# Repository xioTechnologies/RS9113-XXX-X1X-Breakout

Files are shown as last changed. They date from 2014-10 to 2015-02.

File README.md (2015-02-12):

RS9113-XXX-X1X-Breakout
=======================

Breakboard for the Redpine Signals [RS9113-XXX-X1X](http://www.redpinesignals.com/Modules/Internet_of_Things/Connection_Family/RS9113.php) Wi-Fi module.  Includes pull-down resistors as per datasheet.

The silkscreen overlaps copper pads with the intention that this is corrected by the PCB fabrication supplier.

Photo (with connections for UART)
---------------------------------


PCB Preview from OSH Park
-------------------------
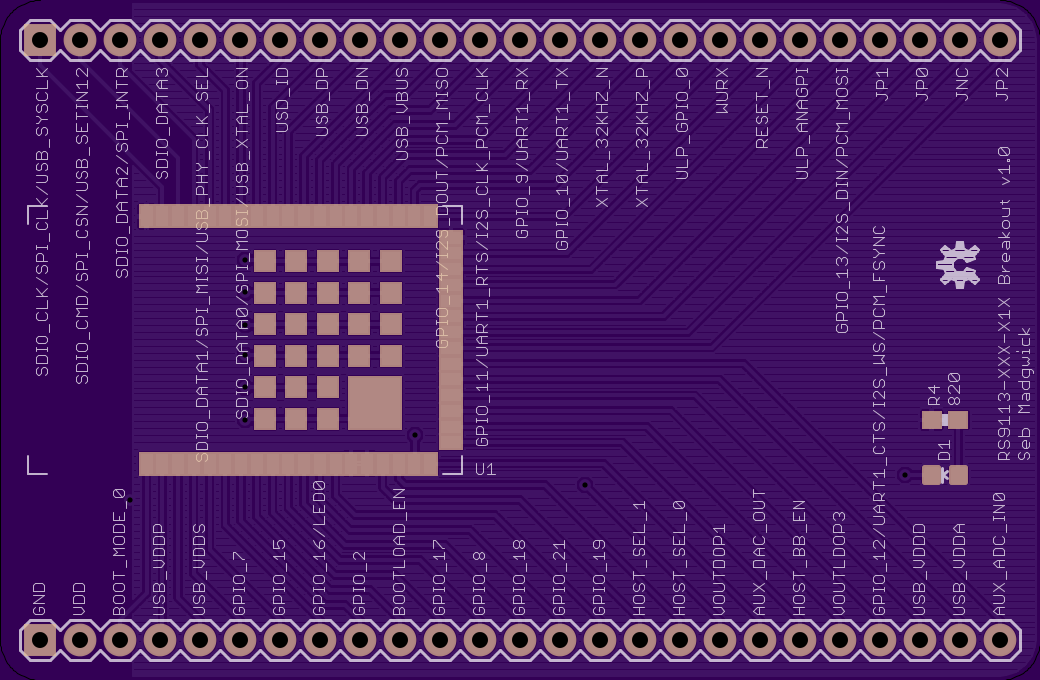
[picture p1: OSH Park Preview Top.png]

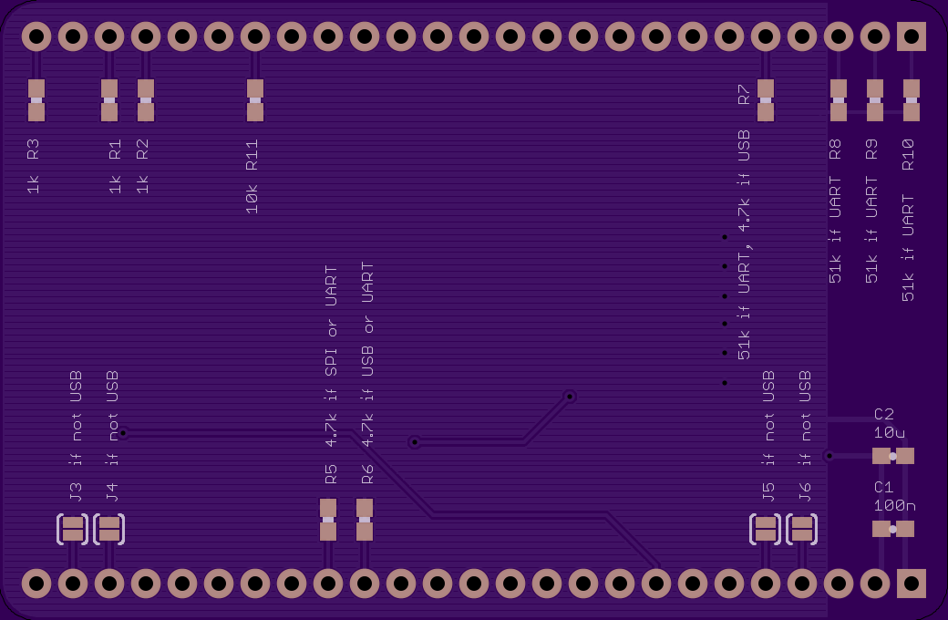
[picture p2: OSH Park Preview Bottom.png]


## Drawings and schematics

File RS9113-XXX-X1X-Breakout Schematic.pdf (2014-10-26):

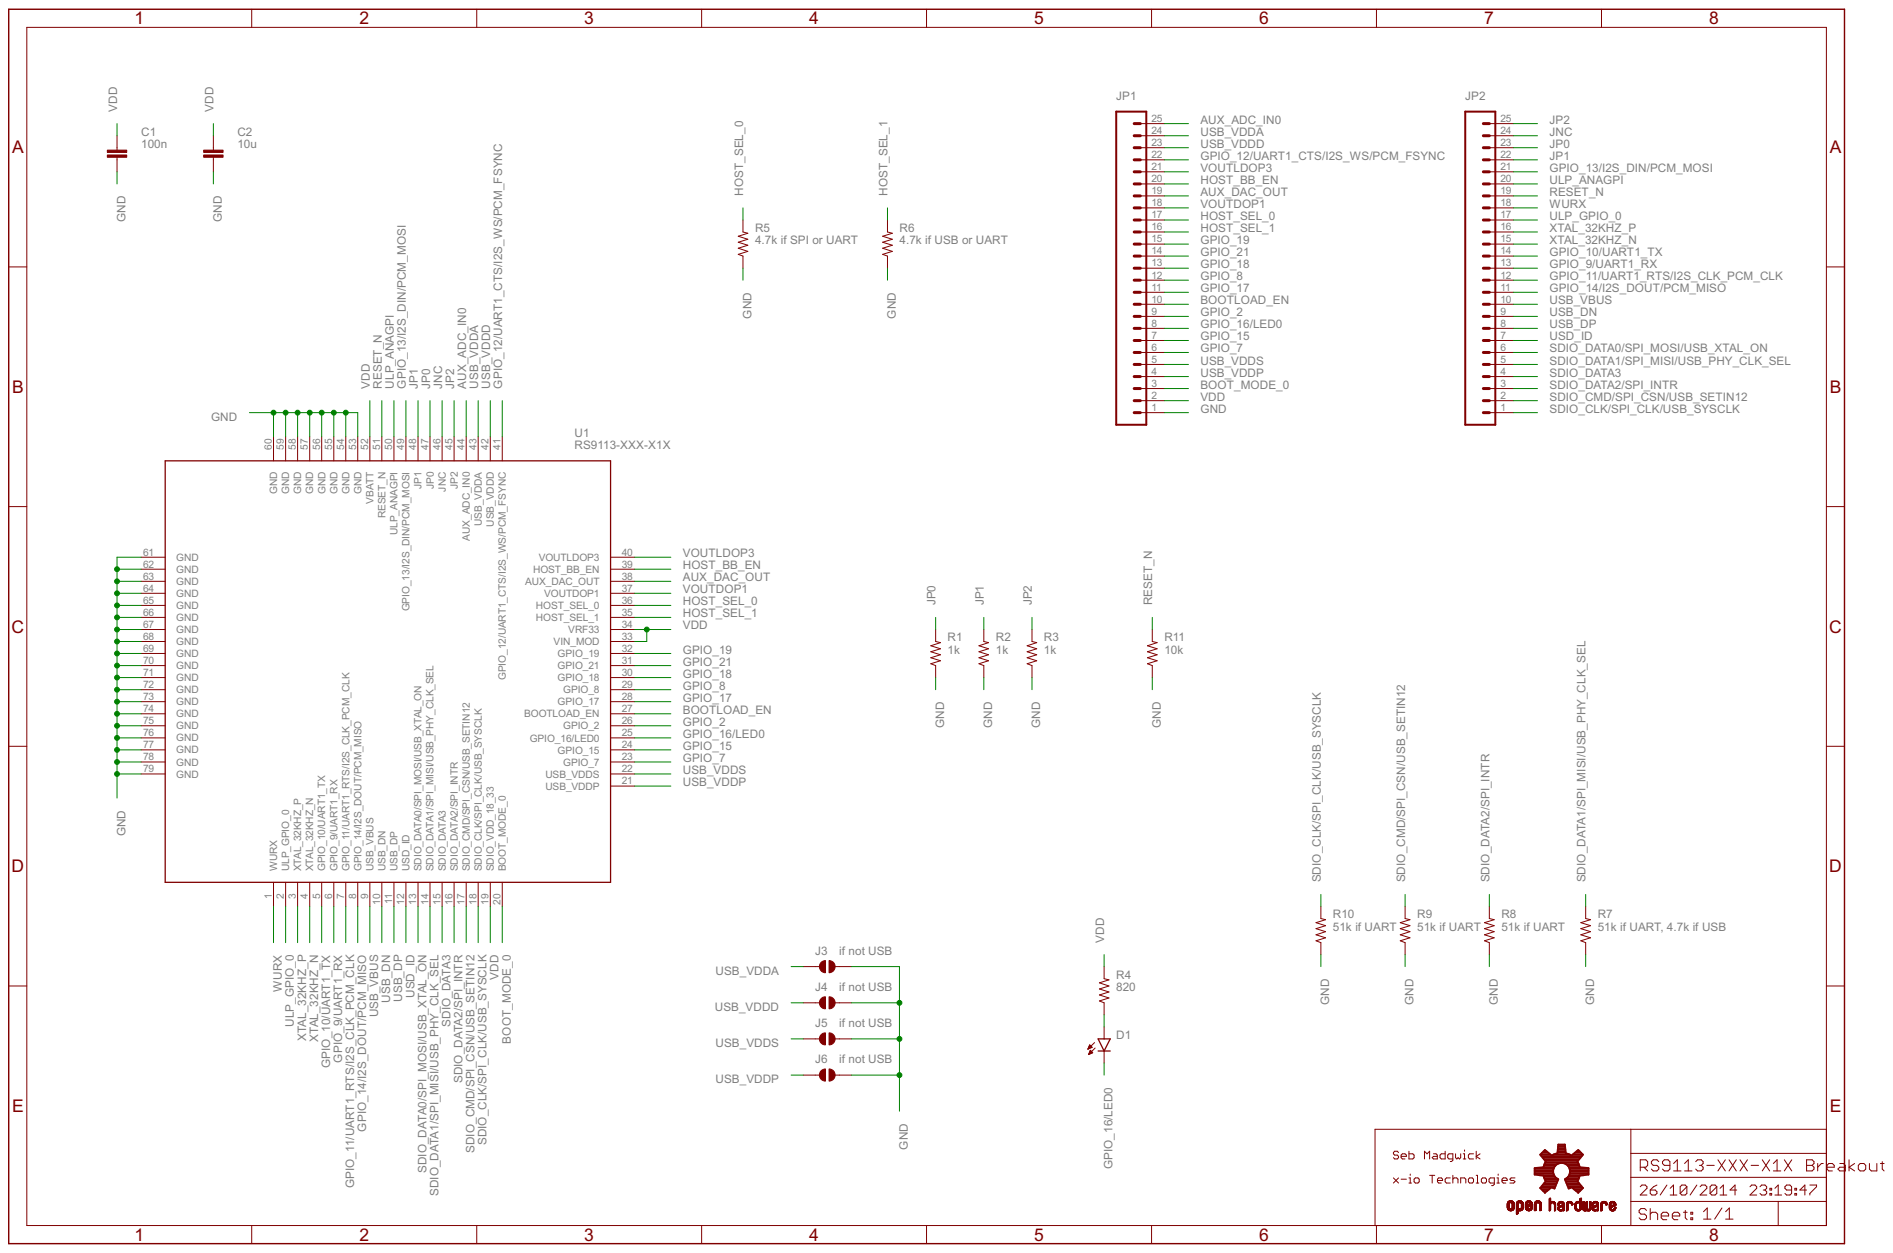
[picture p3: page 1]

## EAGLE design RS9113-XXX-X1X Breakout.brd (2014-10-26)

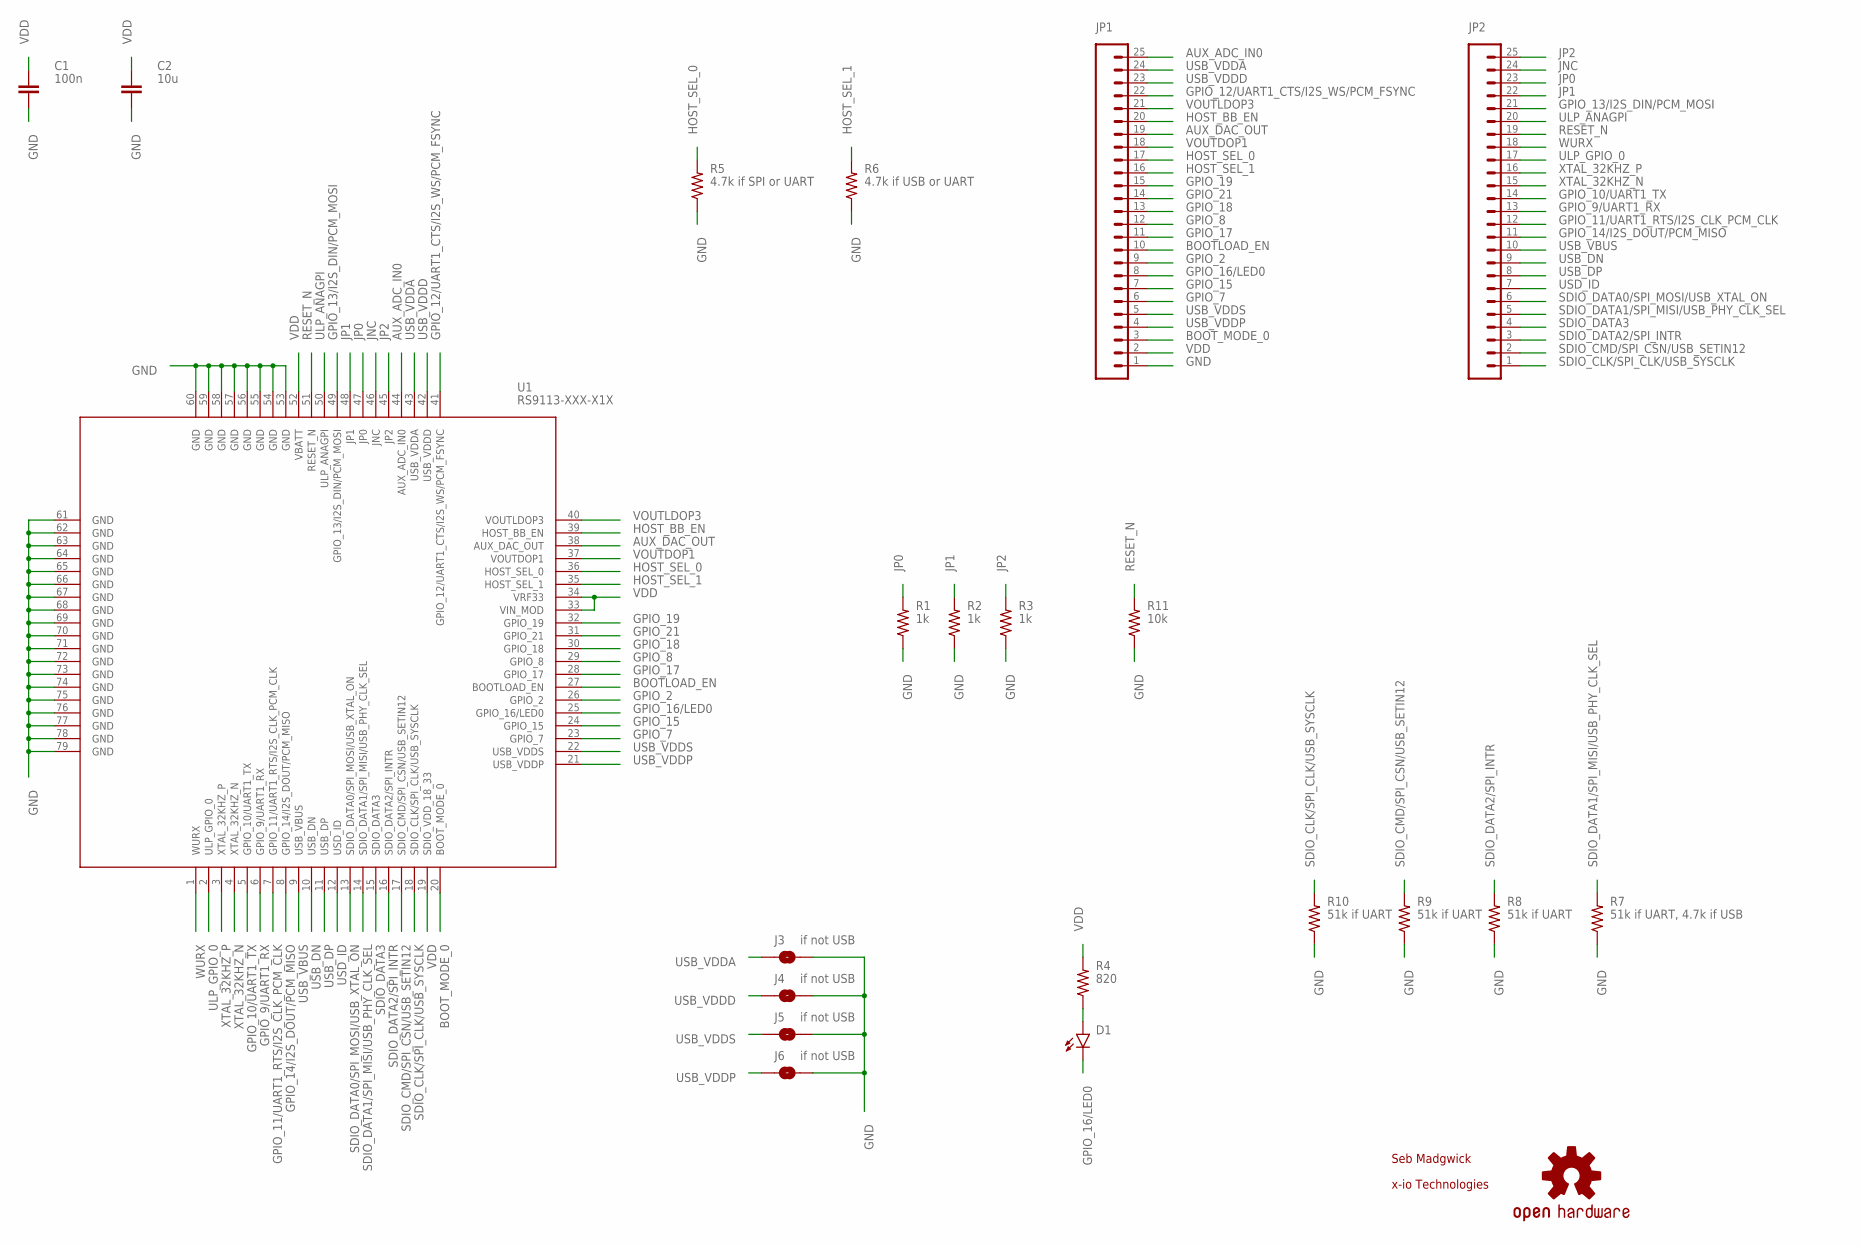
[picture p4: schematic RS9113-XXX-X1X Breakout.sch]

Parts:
C1: 100n; 0603-CAP
C2: 10u; 0603-CAP
D1: GREEN; LED-0603
J3, J4, J5, J6: if not USB; SJ_2S-NO
JP1, JP2: M25PTH; 1X25
LOGO1: OSHW-LOGOS; OSHW-LOGO-S
R1, R2, R3: 1k; 0603-RES
R4: 820; 0603-RES
R5: 4.7k if SPI or UART; 0603-RES
R6: 4.7k if USB or UART; 0603-RES
R7: 51k if UART, 4.7k if USB; 0603-RES
R8, R9, R10: 51k if UART; 0603-RES
R11: 10k; 0603-RES
U1: RS9113-XXX-X1X

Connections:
AUX_ADC_IN0: JP1.25, U1.44 (AUX_ADC_IN0)
AUX_DAC_OUT: JP1.19, U1.38 (AUX_DAC_OUT)
BOOTLOAD_EN: JP1.10, U1.27 (BOOTLOAD_EN)
BOOT_MODE_0: JP1.3, U1.20 (BOOT_MODE_0)
GND: C1.2, C2.2, J3.1, J4.1, J5.1, J6.1, JP1.1, R1.1, R2.1, R3.1, R5.1, R6.1, R7.1, R8.1, R9.1, R10.1, R11.1, U1.53 (GND), U1.54 (GND), U1.55 (GND), U1.56 (GND), U1.57 (GND), U1.58 (GND), U1.59 (GND), U1.60 (GND), U1.61 (GND), U1.62 (GND), U1.63 (GND), U1.64 (GND), U1.65 (GND), U1.66 (GND), U1.67 (GND), U1.68 (GND), U1.69 (GND), U1.70 (GND), U1.71 (GND), U1.72 (GND), U1.73 (GND), U1.74 (GND), U1.75 (GND), U1.76 (GND), U1.77 (GND), U1.78 (GND), U1.79 (GND)
GPIO_2: JP1.9, U1.26 (GPIO_2)
GPIO_7: JP1.6, U1.23 (GPIO_7)
GPIO_8: JP1.12, U1.29 (GPIO_8)
GPIO_9/UART1_RX: JP2.13, U1.6 (GPIO_9/UART1_RX)
GPIO_10/UART1_TX: JP2.14, U1.5 (GPIO_10/UART1_TX)
GPIO_11/UART1_RTS/I2S_CLK_PCM_CLK: JP2.12, U1.7 (GPIO_11/UART1_RTS/I2S_CLK_PCM_CLK)
GPIO_12/UART1_CTS/I2S_WS/PCM_FSYNC: JP1.22, U1.41 (GPIO_12/UART1_CTS/I2S_WS/PCM_FSYNC)
GPIO_13/I2S_DIN/PCM_MOSI: JP2.21, U1.49 (GPIO_13/I2S_DIN/PCM_MOSI)
GPIO_14/I2S_DOUT/PCM_MISO: JP2.11, U1.8 (GPIO_14/I2S_DOUT/PCM_MISO)
GPIO_15: JP1.7, U1.24 (GPIO_15)
GPIO_16/LED0: D1.C, JP1.8, U1.25 (GPIO_16/LED0)
GPIO_17: JP1.11, U1.28 (GPIO_17)
GPIO_18: JP1.13, U1.30 (GPIO_18)
GPIO_19: JP1.15, U1.32 (GPIO_19)
GPIO_21: JP1.14, U1.31 (GPIO_21)
HOST_BB_EN: JP1.20, U1.39 (HOST_BB_EN)
HOST_SEL_0: JP1.17, R5.2, U1.36 (HOST_SEL_0)
HOST_SEL_1: JP1.16, R6.2, U1.35 (HOST_SEL_1)
JNC: JP2.24, U1.46 (JNC)
JP0: JP2.23, R1.2, U1.47 (JP0)
JP1: JP2.22, R2.2, U1.48 (JP1)
JP2: JP2.25, R3.2, U1.45 (JP2)
unnamed: D1.A, R4.1
RESET_N: JP2.19, R11.2, U1.51 (RESET_N)
SDIO_CLK/SPI_CLK/USB_SYSCLK: JP2.1, R10.2, U1.18 (SDIO_CLK/SPI_CLK/USB_SYSCLK)
SDIO_CMD/SPI_CSN/USB_SETIN12: JP2.2, R9.2, U1.17 (SDIO_CMD/SPI_CSN/USB_SETIN12)
SDIO_DATA0/SPI_MOSI/USB_XTAL_ON: JP2.6, U1.13 (SDIO_DATA0/SPI_MOSI/USB_XTAL_ON)
SDIO_DATA1/SPI_MISI/USB_PHY_CLK_SEL: JP2.5, R7.2, U1.14 (SDIO_DATA1/SPI_MISI/USB_PHY_CLK_SEL)
SDIO_DATA2/SPI_INTR: JP2.3, R8.2, U1.16 (SDIO_DATA2/SPI_INTR)
SDIO_DATA3: JP2.4, U1.15 (SDIO_DATA3)
ULP_ANAGPI: JP2.20, U1.50 (ULP_ANAGPI)
ULP_GPIO_0: JP2.17, U1.2 (ULP_GPIO_0)
USB_DN: JP2.9, U1.10 (USB_DN)
USB_DP: JP2.8, U1.11 (USB_DP)
USB_VBUS: JP2.10, U1.9 (USB_VBUS)
USB_VDDA: J3.2, JP1.24, U1.43 (USB_VDDA)
USB_VDDD: J4.2, JP1.23, U1.42 (USB_VDDD)
USB_VDDP: J6.2, JP1.4, U1.21 (USB_VDDP)
USB_VDDS: J5.2, JP1.5, U1.22 (USB_VDDS)
USD_ID: JP2.7, U1.12 (USD_ID)
VDD: C1.1, C2.1, JP1.2, R4.2, U1.19 (SDIO_VDD_18_33), U1.33 (VIN_MOD), U1.34 (VRF33), U1.52 (VBATT)
VOUTDOP1: JP1.18, U1.37 (VOUTDOP1)
VOUTLDOP3: JP1.21, U1.40 (VOUTLDOP3)
WURX: JP2.18, U1.1 (WURX)
XTAL_32KHZ_N: JP2.15, U1.4 (XTAL_32KHZ_N)
XTAL_32KHZ_P: JP2.16, U1.3 (XTAL_32KHZ_P)

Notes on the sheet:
Seb Madgwick
x-io Technologies

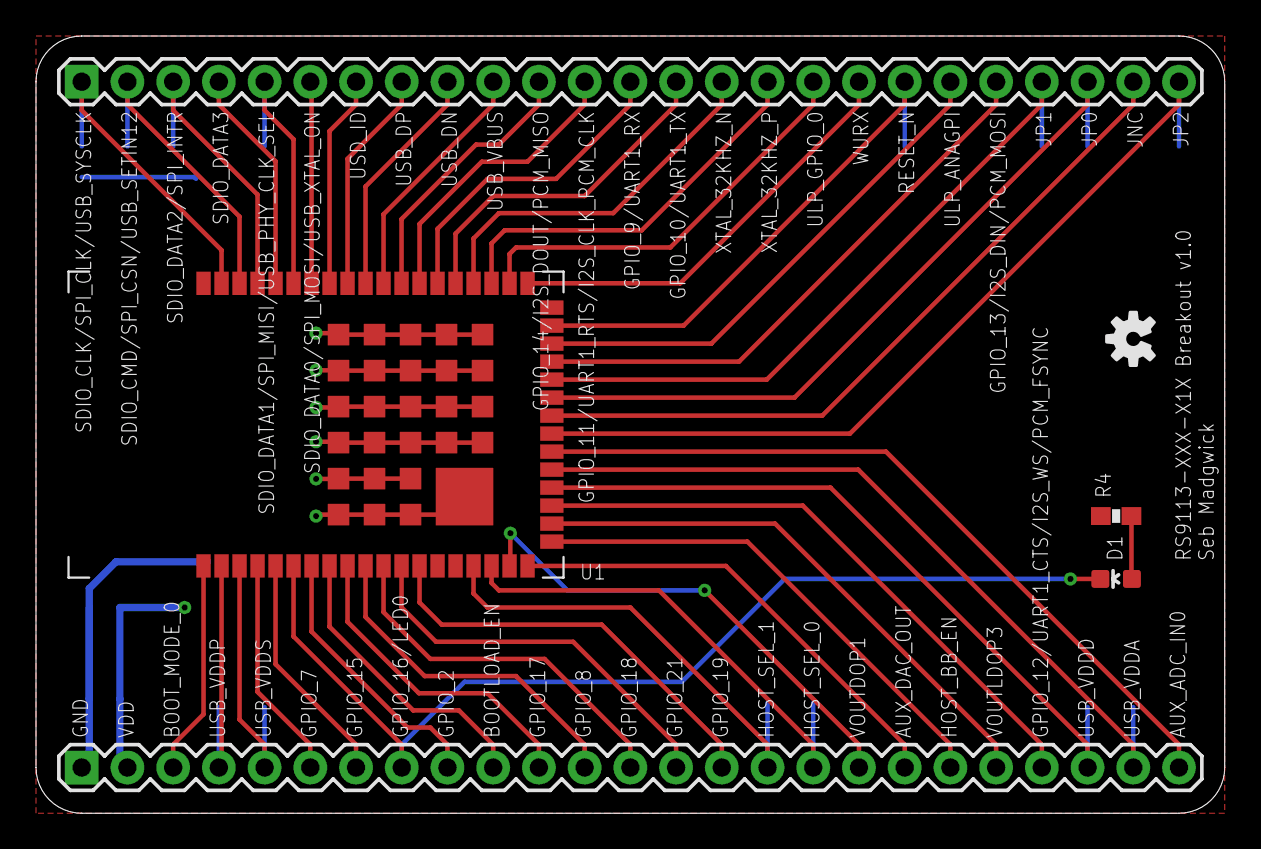
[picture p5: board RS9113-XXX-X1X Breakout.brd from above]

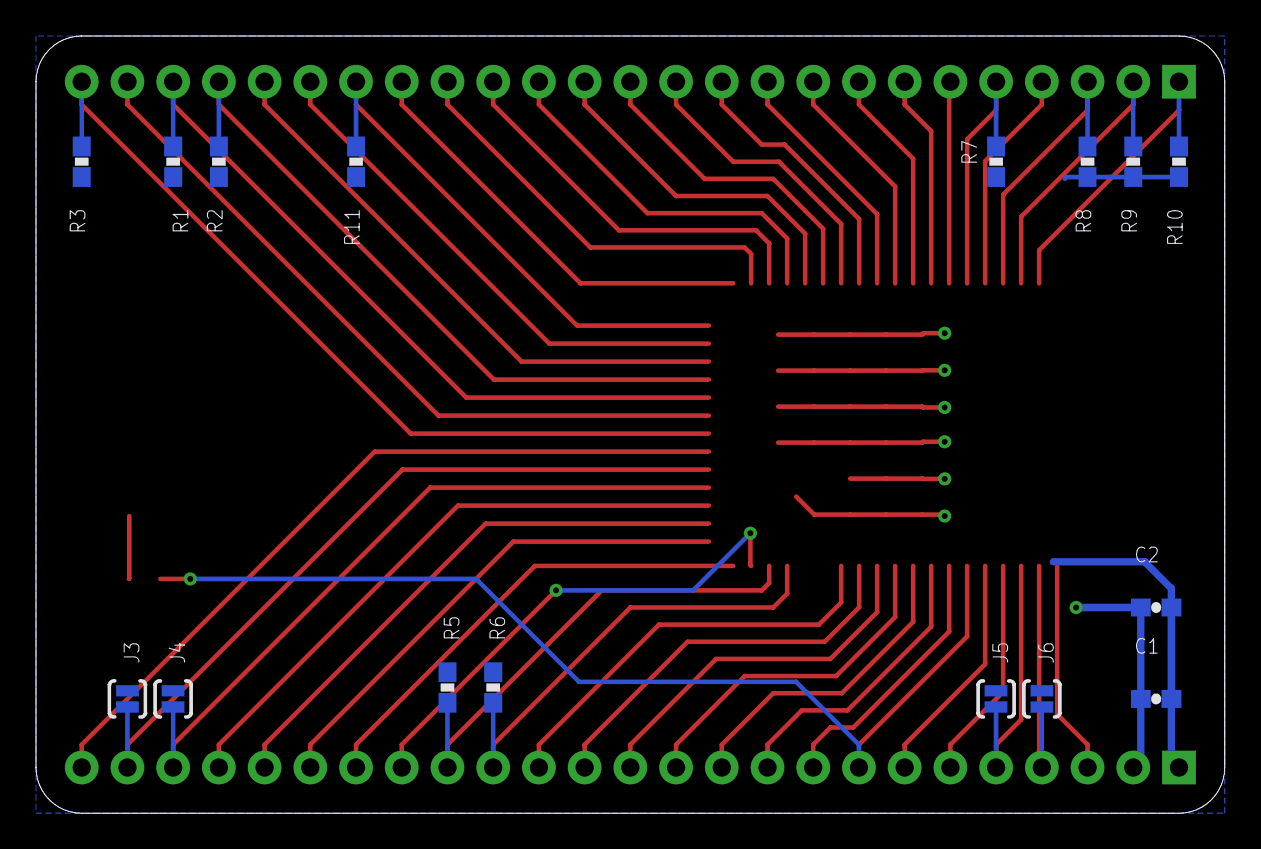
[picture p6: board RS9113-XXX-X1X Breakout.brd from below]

Board: 2 copper layers, 66.0 x 43.2 mm, 22 parts (16 on the bottom side), 51 nets.

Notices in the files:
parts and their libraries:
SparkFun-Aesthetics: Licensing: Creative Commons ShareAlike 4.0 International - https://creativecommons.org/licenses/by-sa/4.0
